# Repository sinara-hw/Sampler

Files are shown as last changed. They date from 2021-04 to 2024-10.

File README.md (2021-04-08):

# Sampler
ARTIQ - compatible 8 channel 16bit 1MS/s ADC card in EEM standard

## Design Files

Design files (schematics, PCB layouts, BOMs) can be found at [Sampler/Releases](https://github.com/sinara-hw/Sampler/releases).

## Wiki

More information can be found on the [wiki](https://github.com/sinara-hw/Sampler/wiki).

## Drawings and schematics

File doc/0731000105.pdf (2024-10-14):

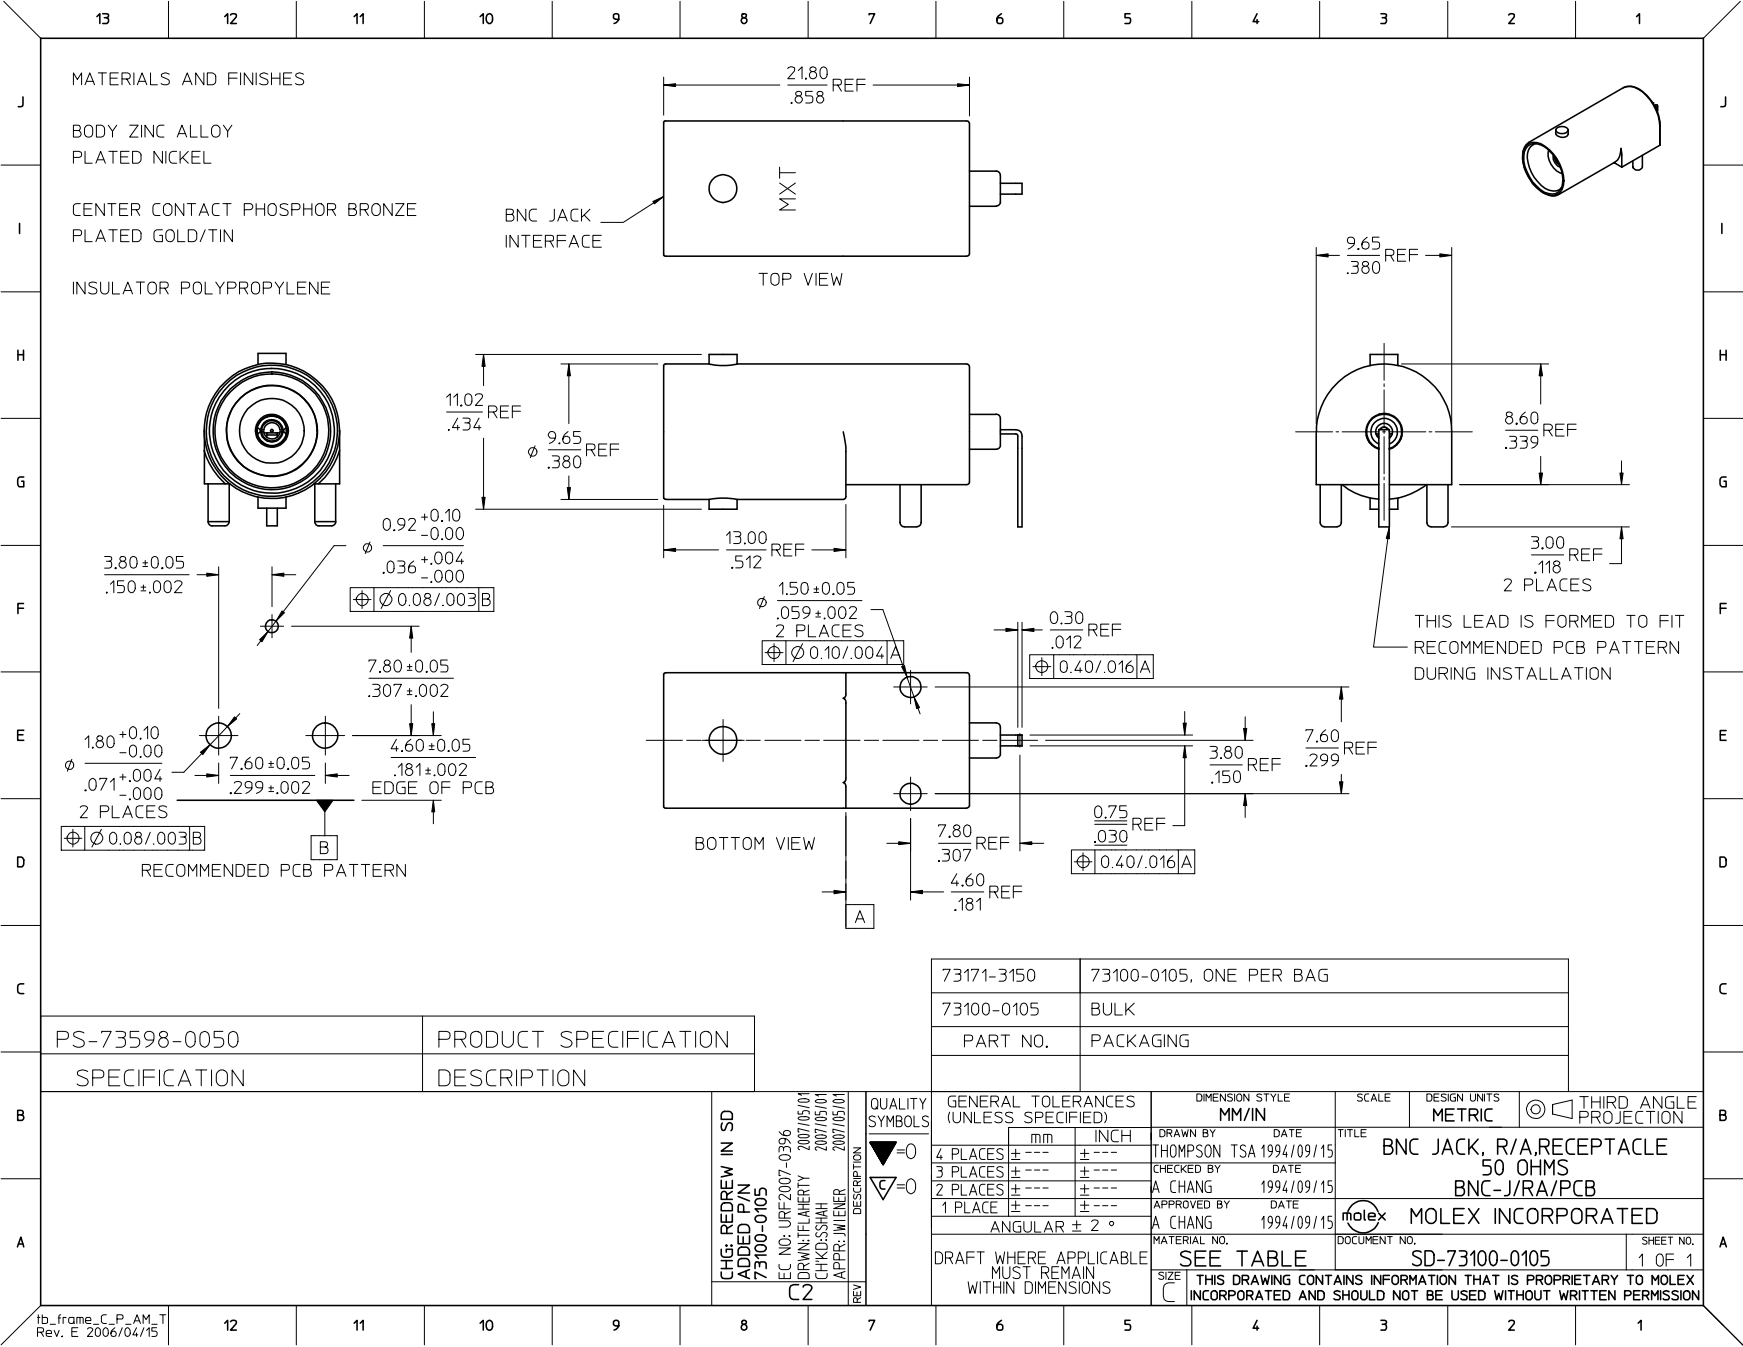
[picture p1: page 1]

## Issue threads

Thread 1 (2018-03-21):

Unexpectedly high noise in 1000x gain range

jordens, 2018-03-21:
Is 4.4 µV RMS, was 3.7 with Novogorny (14.3 vs 9.7 LSB RMS). The bandwidth limitation should be the same (the INA). Different full scale voltage (12/10) taken into account.
Maybe investigate this.

hartytp, 2018-03-23:
Firstly, to remind myself what we expect here.

- Input noise of the AD8253 at G=1k is 10nV/rtHz + 5pA/rtHz
- With 50R termination, that goes to ground through a pair of 1.8k resistors
- Assuming I've understood the [noise model](http://www.analog.com/media/en/training-seminars/tutorials/MT-065.pdf), we have: n = sqrt(10^2 + 5e-3*1.8e3 + 7.6^2)=13nV/rtHz
- 3dB BW=60kHz so (assuming dominant pole) is 96kHz
- Integrated noise is expected to be 4.0uVrms

So, the measured numbers fall roughly +-10% of the calculation. That's about as good an agreement with the theory as I'd expect, so I'm not overly worried about it -- particularly given that we only have 1 data point for each version. My suspicion is that this is just device to device variation, so it would be interesting to see some more statistics (e.g. more channels/more boards).

Note also that I'm not aware of any changes to the design that could cause this (the high-gain noise is dominated by the AFE which is unchanged between designs IIRC).

Closed 2018-04-12.

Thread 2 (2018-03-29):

Sampler v2.0 testing

sotirova, 2018-03-29:
**Noise measurement**:

Configuration:
- Sample rate: 1/12us
- 10k samples per measurement, averaging over 100 measurements
- looking at channels 6 and 7. 6 has the 50R termination on, 7 has it off
- looking at noise as a function of frequency for different gains.

Results:

|gain | noise w/ termination | noise w/o termination|
|---|---|---|
|1 | 1.78LSB (544.3uV) | 1.75LSB (535.6uV) |
|10 | 1.84LSB (56.2uV) | 3.09LSB (94.4uV) |
|100 | 3.47LSB (10.6uV) | 26.02LSB (79.4uV) |
|1000 | 13.87LSB (4.2uV) | 206.3LSB (63.0uV) |

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

Expectations:
- ADC transition noise is 1.5LSB RMS, which should limit the low gain noise measurement
- BW of ADC driver is 1.1MHz.
- InAmp noise model:
  - for G=1: 45nv/rtHz * sqrt(1.1MHz) * 1.6=72uV For G=1, this gives 0.23LSB*gain, lower for higher gains
  - Noise current BW is presumably 1/(2 * pi * 200k * 82pF) so 10kHz
  - No termination: 5pA/rtHz * 100k * sqrt(10kHz) * 1.6 = 80uV = 0.26LSB*gain
(actually, that's not totally correct, because the RFI filter reduces this slightly...)
  - Termination: 5pA/rtHz * 2k *sqrt(1.1MHz) * 1.6 = 16uV, so negligible

- ADC driver:
  - Johnson noise from 20k resistors is 18nV/rtHz so negligible
  - OpAmp is low noise compared to InAmp

So, expected noise is:

|gain | noise w/ termination | noie w/o termination|
|---|---|---|
| 1 | 1.5LSB | 1.5LSB |
| 10 | ... | ... |
| 100 | ... | ... |
| 1000 | ... | ... |

Comments:

- Spurs are most likely due to pickup.
- Adding/removing the two screening cans doesn't make a noticeable difference to the data
- Running from a linear PSU/wall wart doesn't make a difference, nor does connecting the linear PSU -ve output to GND.

hartytp, 2018-03-29:
Expected noise (summing InAmp vn + in and ADC contributions):

|gain|noise w/ termination|noise w/o termination|
|---|---|---|
| 1 | 1.5LSB (460uV) | 1.5LSB (460uV) |
| 10 | 1.6LSB (50uV) | 2.6LSB (80uV) |
| 100 | 4.8LSB (14.7uV) | 21LSB (64uV) |
| 1000 | 14.4 LSB (4.4uV) | 206LSB (63uV) |

Done on paper, so may contain mistakes ;) but suggests that the numbers we see are consistent with datasheet values.

- For no-termination, taking the current noise BW as 1/(2*pi*200k*82pF) = 10k

PS NB factor of 1.6 in BW above should be *inside* the sqrt.

hartytp, 2018-03-29:
Note also that we decided to increase the ADC driver BW to 1.1MHz for the v2 design. That makes the noise worse for higher gains than in the v1.0 design. The motivation for this was some simulations I did for laser intensity servo loops, where I found that increasing the ADC BW gave a decent improvement in servo BW/settling time.

Personally, I think the extra BW is worth the increased noise (which is still very low for the applications I have in mind). But, if anyone feels that we should tweak the BW for the v2.1 design, I'm happy to reconsider. If we do decrease the BW, we could increase the capacitor before the ADC, which might help to reduce sampling transients (although, we don't currently have any evidence that these are a problem in the current design).

sotirova, 2018-04-16:
**Bandwidth measurement**

We measured the bandwidth as a function of gain for both small and large input signal - ou measurements are consistent with what we expect to see from the design so everything seems to be working fine.

The large-signal bandwidths are very similar to the small-signal bandwidths.

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

Method:

- 1e4 samples
- sample rate 1/1.26e-5 Hz
- sampling channel 7 (no termination) driven by sinusoid from Keysight 33500B generator
- Small-signal BW measured using 2Vpp/gain
- Large-signal bandwidth measured using 15Vpp/gain

hartytp, 2018-04-18:
List of tests:
- [x] Noise spectrum with 0V inputs (all gains, w + w/o testing)
- [ ] Verify that noise does not depend on input voltage, using batteries as a voltage source (G=1, G=1k)
- [x] Small + large signal BW (all gains)
- [x] Cross-talk (https://github.com/sinara-hw/sinara/issues/489)
- [x] Temp co? Ticked off as not worth measuring. IMHO, feel free to untick if you want this/can be bothered to do it!
- [x] CMMR Ticked off because we measured this on the V1 design and the AFE hasn't changed, so I'm happy trusting that data.
- [x] Harmonic content at some fixed frequency (all gains, large signal?). Ticked off because I don't think this is worth measuring.

hartytp, 2018-04-18:
(baiscally, I'm happy that this board is now well tested, and the other measurements can all be finished off later as and when people really need them!)

Thanks again to all involved in the testing.

Closed 2018-04-27.

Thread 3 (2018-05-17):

gain error

jordens, 2018-05-17:
I am seeing a reading of 5V for 4.875V input and `0x7fff` for 9.76V input (pretty much the magic 1024/1000 error). I can't explain it from the schematics or the datasheets.
@hartytp @gkasprow have you also seen that?
Sampler/v2.1

gkasprow, 2018-05-17:
Was it the same in previous releases/batches?
I measured the DC response on rev1.0 and the difference was caused by the value of the RC filter which caused systematic error. This was fixed in rev 2.
I did not measure the DC response in rev2.x

gkasprow, 2018-05-17:
@jordens I assume you meant four references, REFOUT1..4. Or maybe REF_P2V5 and REF_P2V0?
Did you check the common mode of the ADC input? Maybe for some reason the DC offset appeared.
Please check also REF_P2V5 and REF_P2V0 on pin 1 and 7 of IC5. If you already checked, please check REFOUT1..4.

hartytp, 2018-05-17:
I don't think we saw that, no (although, I didn't do the testing myself so I can't be 100% sure).

jordens, 2018-05-18:
On one board REFOUT1,2 are 4.87V, REFOUT3,4 are ~4.9V. On another all four are 4.95V. All are definitely below 5.000V.

gkasprow, 2018-05-18:
So this explains the observation.
Can you measure voltage just at the C12 or pin 8 of ADC?

gkasprow, 2018-05-18:
Look at this voltage with scope as well. There is very little chance that reference oscillates.
I will recreate the issue but not earlier than Tuesday.
The ADC reference can be applied in two ways.
First - delivered to the REFOUT1..4, but then R10 must be removed (REFBFEN shorted to GND) and reference applied directly.
Second - delivered to the REF pin where it overrides internal reference. Internal reference has 250uA output current so can be easily overrided by external one.
It looks like the internal reference buffers are not real rail to rail amplifiers.
Did you check if the supply voltage is 5V? If it is slightly lower, that may be an issue and should be increased even to 5.25V by modification of 1 resistor. In such case this issue could be not detected on previous boards.
Another solution is to disable the buffers and apply the reference directly.

jordens, 2018-05-18:
No oscillations that I can see on REF or REFOUT1...4. I measured the 5V reference at C12.
P5V0A is also below 5V (~4.95V). Adding ~300k in parallel with R29 fixes it.

jordens, 2018-05-18:
I don't really like VDD=5.25V. And I don't know whether REFBUFEN=0, REFOUT1...4=5V, and VDD~4.99V would work. We could just simplify everything and lower the AFE gain and go with REF=4.096V. That also avoids complaints about "the ADC not doing 10.000V" and makes the math easier. Was/is the 1dB THD and 0.5dB SNR gain really worth it?

jordens, 2018-05-18:
I'll leave open until the fix has been committed to the repo or until this has landed on an errata list.

jordens, 2018-05-18:
I see you just did that. ;) Closing.

gkasprow, 2018-05-18:
5.25 is still within operating range and far below maximum voltage (6V). Another option is to connect the REF to all ref outputs.
Since many Samplers were produced, changing the reference value now may cause frustration at some point. We would have to indicate it on the panel.

jordens, 2018-05-18:
5.25V is at the end of the specified range for VDD.
If you connect a 5V REF to all REFOUT, are you sure that will work with e.g. VDD=4.99V (what I wondered above)?
Supporting two different VREF in the code is not that hard. It's probably less inconvenient than running around and patching all Sampler boards with the issue.

gkasprow, 2018-05-18:
To change reference, you need to replace the chip anyway.
That's true, taking into account tolerances of resistors and regulator reference, one can exceed 5.25V. We would need to use 0.1% resistors. VADJ tolerance is 12mV (roughly 1%) and set 5.2V to make sure 5.25 will not be exceeded.
Direct connection needs testing, but it's easy to be done.
But probably 4.096V range would be more stable in long-term.
It would be hard to achieve +/-10V range with 4.096 reference due to missing matched resistive dividers that provide such division rate.

jordens, 2018-05-18:
Yes. More a lesson for the future. I am OK with 5.2V for now.
I meant +- 10.24 V range (2.5 gain, easy conversion math, and +10 V strictly included, also what many other products do).

hartytp, 2018-05-18:
@jordens Thanks for tracking this down!

I wonder why we didn't see it on the board we tested. Was there a change between v2.0 and v2.1 that affects this? Did we get lucky with component tolerances giving us a higher supply voltage on the board we tested? Or, did we just miss it? Anyway, I'll look at it when I'm back in the lab.

Assuming the dividers work out okay (someone needs to sketch out what they would be), I agree that going to a +-10.24 span (4.096Vref) sounds like the right idea. For the time being, I'll apply the same patch as @jordens to increase the supply voltage to 5.2V.

gkasprow, 2018-05-18:
We can move to 1/5 gain easily, we have:
2x5k and 2x10k in one package.
At the moment we have gain of 10+10 /5 = 4
We can combine 10+10+5/5 = 5.
We can make it in next revision.

hartytp, 2018-05-18:
@gkasprow what dividers would you use on the reference voltage to create the common-mode offsets?

gkasprow, 2018-05-18:
Exactly.

gkasprow, 2018-07-25:
fixed

Closed 2018-05-18.

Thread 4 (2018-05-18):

Sampler errata

gkasprow, 2018-05-18:
- ~increase 5V to 5.25 to make more room for REF buffer.~
- [x] Use 4.096V reference and change AFE gain.

gkasprow, 2018-07-25:
fixed

Closed 2018-07-25.

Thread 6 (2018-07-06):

LDO + diodes

hartytp, 2018-07-06:
cf Zotino (need to check other designs as well...)

gkasprow, 2018-07-25:
ADC do not have negative rail, opamps don't care since they don't have GND terminal.
Sampler supply has power sequencing mechanism implemented so don't think we need Shottky diodes at the LDO output. Standard TVS works fine.

Closed 2018-07-27.

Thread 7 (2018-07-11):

SMPS current setting resistor should be 36k

hartytp, 2018-07-11:
cf https://github.com/sinara-hw/Zotino/issues/10

gkasprow, 2018-07-11:
@hartytp You are right. After I soldered 36K, the voltage dropped to +/-13V and current drawn from 12V dropped from 0.22A to 0.19A

Closed 2018-07-25.

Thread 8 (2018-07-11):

SMPS rating

hartytp, 2018-07-11:
https://github.com/sinara-hw/Zotino/issues/13

gkasprow, 2018-07-25:
In Sampler the IDC connector supply rails are disconnected by default.
I added a 0R resistor that can enable +12V as well.

Closed 2018-07-25.

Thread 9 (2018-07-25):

v2.2 review

gkasprow, 2018-07-25:
@hartytp @jordens I want to make production run of v2.2
Please have a look at the [schematics](https://github.com/sinara-hw/Sampler/releases/tag/Sampler%2Fv2.2rc1)
I modified the ADC range, input stage gain and reference generation.

hartytp, 2018-07-25:
Thanks Greg. I'll look at it with fresh eyes in the morning.

hartytp, 2018-07-25:
Before I forget though, there are a few issues in https://github.com/sinara-hw/meta/issues that are relevant and would be nice to fix now (e.g. if it's easy, it would be nice to swap the EEM connector ordering).

hartytp, 2018-07-26:
Relevant "meta" issues are:
- https://github.com/sinara-hw/meta/issues/3
- https://github.com/sinara-hw/meta/issues/2
- https://github.com/sinara-hw/meta/issues/1

Only https://github.com/sinara-hw/meta/issues/1 affects the schematic/layout.

gkasprow, 2018-07-26:
OK, I will swap the EEM connectors

gkasprow, 2018-07-26:
done.

hartytp, 2018-07-27:
Do you need to make any PCB changes for the EMC gaskets (e.g. ensure that mount holes are connected to PCB ground)?

Otherwise, looks good to me. Thanks!

gkasprow, 2018-07-27:
OK, I changed the holes to plated and connected to GND.

jordens, 2018-07-27:
Woa. Why exactly was that done? Is it needed and is this the right moment and place to do it?
* AFAICT this is the only board that has this. Now this is the only point where the crate connects to GND.
* It's irrelevant for for EMC shielding AFAICT. The slot between the board and the panel is still there.

hartytp, 2018-07-27:
@jordens my understanding is that we agreed that all EEM front panels should connect to ground at the PCB, rather than relying on the long inductive loop of the IDC to do it.

gkasprow, 2018-07-27:
Guys, I can add 0R not mounted by default.

gkasprow, 2018-07-27:
I will make these 0R mounted by default.

jordens, 2018-07-27:
I am ok with reliably connecting the front panel to GND. I just have a problem with doing it in one place through single a connection that does not look like it's meant to ground the entire crate: Does that angle bracket reliably connect the front panel, does it cut through the passivation? I'd like to first have a consensus how we want to "properly" ground the case and after that start connecting to the case in various places. I.e. I'd rather leave this connection open now.
Where are we relaibly connecting to the crate currently? AFAICT:
* Kasli SFPs: I don't think they get through the passivation reliably. Or does it work somewhat because the inside of the cutout is freshly cut?
* Kasli Power: No
* Crate to EEM front panel: Not cutting through the passivation on the non-shielded crates, yes on the shielded crates
* Zotino HD68 shield, Grabber shield, HD68IDC shield: probably not even pressing against it
* DIO-RJ45: same as Kasli-SFP

hartytp, 2018-07-27:
> I'd like to first have a consensus how we want to "properly" ground the case and after that start connecting to the case in various places. I

Absolutely agreed.

I'd like to try to get this consensus before we make more EEMs to avoid spreading bad design decisions further.

> I just have a problem with doing it in one place through single a connection that does not look like it's meant to ground the entire crate

When you say "ground the entire crate" you mean "join the Kasli/EEM ground to the crate ground", right?

> Does that angle bracket reliably connect the front panel, does it cut through the passivatedA?

@gkasprow

> Where are we relaibly connecting to the crate currently? AFAICT:

I can't remember the details now (@cjbe) but, I've had a few cases where EEMs have grounded the chassis in unexpected ways, causing surprising issues. Currently, the crate is neither properly isolated nor properly connected to the EEMs, which seems like the worst possible situation.

AFAICT, the best solution is to agree that going forwards that all EEMs should ground to the crate via their front panels.

hartytp, 2018-07-27:
> Where are we relaibly connecting to the crate currently? AFAICT:

NB As I said, we're preparing to buy a fresh batch of EEMs, so the plan would be to ensure that this fix is applied to all EEMs produced from now on. That way, it's not just sampler that does the grounding.

We can leave 0R resistors so users can isolate the grounds if they need to.

jordens, 2018-07-27:
All correct. But there are dozens of crates out there with the current configuration. If any user wants to use a new module we need to come up with a way to handle this properly.

hartytp, 2018-07-27:
Okay, so we agree that the long-term solution is connecting the FP to the circuit ground (modulo the issue you raise about checking that the way Greg is doing this will actually work)?

> But there are dozens of crates out there with the current configuration. If any user wants to use a new module we need to come up with a way to handle this properly.

Well, the current situation is bad in a few ways. I'm not sure that adding the grounding on new EEMs makes it worse. And, in any case, there are 0R resistors which can be DNPd

Personally, I'd advice users to find a way of grounding their Kaslis to their crates.

jordens, 2018-07-27:
These options to rework the board are not satisfactory solutions IMHO. It's undocumented, hard to get through to the board house or the end user without causing delays/misunderstandings. The default needs to be consistent and correct. The burden of proof is with the proposed new solution, not the status quo. Does this attempt at grounding the panel improve the situation? Given the current state, I don't see how it has a positive effect on safety, on EMI, on consistency, and grounding quality. The only areas that come to mind are EMI and ESD, right? Since nobody wants to run current through this connection, I don't see how the power grounding problem is affected or resolved. If those new Sampler boards won't be manufactured with the EMI lip panels systematically or if the angle brackets are not meant to or can't reliably connect the panel then the default should be DNP and once we have the full fleet updated we can switch the default BOM.

gkasprow, 2018-07-27:
I released production documentation with grounding resistors DNP. One can request their assembly during ordering or mount them later.

hartytp, 2018-07-27:
> The default needs to be consistent and correct.

Yes

> The burden of proof is with the proposed new solution, not the status quo

Sure: I think we all agree that the current status quo was not properly thought through and is not a good solution. Changing hastily to a new solution without due thought just multiplies the problems. So, let's see if we can settle on something better...

Currently, the EEM system, including power supply, tends to get grounded through unexpected/surprising paths. e.g. pressure put on an SFP cage that connects it to a front pannel, or an RJ45 DIO (grabber connectors?). That leads to unexpected and ill-defined grounding paths -- potentially involving sensitive lab equipment -- which is the absolute worst situation.

The proposal is to attempt to tie the circuit grounds to the chassis ground via their FPs. Lots of chassis provide grounding bolts or other grounding solutions, which we'd tie to a suitable ground point (e.g. all our racks are grounded, as are our optics tables).
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
hartytp, 2018-07-28:
The issues I'm referring to, which were already posted, are things like the RJ45 boards connecting the circuit ground to chassis ground atm. That lead to an odd case where when the 12V connector was mis-wired (and missing a ground connection) Kasli only powered on when an RJ45 board was plugged in (the RJ45 shield connected Kasli to the rack ground, which was electrically earthed). I've seen similar issues with the SFP cages on Kasli which can make intermittent contact with the FP in at least one version of the FPs we have.

NB If we defloat the SMAs on Urukul (as we've agreed to do IIRC) then those will tie Urukul's circuit ground to the PCB ground in any case.

@sbourdeauducq what's your point here? Are you arguing that our current grounding arrangement isn't unsatisfactory?

hartytp, 2018-07-28:
AFAICT, the only good reason that's been raised not to connect the FP ground to circuit ground is if it won't actually work properly (e.g. due to anodisation of the FP).

sbourdeauducq, 2018-07-28:
No, I just want to make sure that @cjbe's problems get addressed in this iteration, so that we end up with 2 different grounding schemes to deal with and not 3.

hartytp, 2018-07-28:
Another "surprising" issue I've seen with the current grounding arrangement (reported elsewhere, but repeated for those who weren't following that discussion).

Before I de-floated the clock input connectors on Kasli, I was driving a floating Kasli board clock input from a synth. That lead to the synth ESD protection tripping, which is something I take very seriously, as I've seen this kill 20k synths before. De-floating the SMA fixed the problem. However, if one does this without grounding Kasli via the chassis (or some other suitable means) then the only electrical ground is via the synth/clock SMA, which is not a good place to be in at all. To fix this, I ended up both defloating the SMA and adding a grounding strap to my Kasli to bond it to my main earthing ground.

All the grounding issues that I'm aware of our group having seen have been reported and discussed. AFAICT, they will all be solved by connecting the EEMs to a grounded chassis, which is effectively what we're doing now.

hartytp, 2018-07-28:
Another way of putting all this:
- In some cases it is necessary to isolate grounds for noise purposes
- however, the correct approach to this is not to isolate all grounds by default (what we did in v1 boards effectively), as that creates the problems we've seen
- instead, a better solution is to tie all grounds together by default, but to give users the option of isolating ground loops in the rare cases that it's actually required. This is what I'd like to see done in v2.0. eg leaving the plastic insulating washers in to allow us to float clock SMAs if we want to, but by default using 0R resistors to ground all SMAs to the chassis/PCB ground

hartytp, 2018-07-29:
Oh and the other "unexpected" grounding issue that crops up in the current design is when the USB cable becomes the only mains grounding point so things can behave differently depending on whether USB connected or not. E.g. the synth was issues only happened when I removed the USB cable

gkasprow, 2018-07-30:
Usually we provide central grounding at the supply rail on the backplane. Since we don't have backplane, such grounding should be done on Kasli or if we use backplane SMPS module, it should be there, just at the DC module output.
In addition, panels are usually connected with GND either directly or using parallel RC network.
In case of RC networ it is to mitigate DC ground-loops and provide short-rircuit for EMI so the RF power path is shorted to chassis as close to the entry as possible.
So the main grounding point is central, close to the supply and all others are to mitigate EMI issues.

hartytp, 2018-07-30:
> So the main grounding point is central, close to the supply and all others are to mitigate EMI issues.

With the new Schroff FPs you're ordering, will the barrel connector on Kasli ground the PSU to the chassis via Kasli's FP?

gkasprow, 2018-07-30:
It should be grounded after the supply passes via CMCs. So grounding at the entry is not best option. It's better to ground it at the panel fixing to the PCB

hartytp, 2018-07-30:
@gkasprow okay.

I'm still not clear though: are you satisfied that the front panels for the next batch of EEMs will provide a good ground connection between the PCB ground and the chassis ground? The old panels did not seem to do that.

gkasprow, 2018-08-04:
The old panels did not do that. New panels are designed to do that so that should be enough.

Closed 2018-08-04.

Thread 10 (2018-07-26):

Lots of text missing in PDFs

hartytp, 2018-07-26:

hartytp, 2018-07-26:
Also, SHDN for IC1.

Some Altium bug?

hartytp, 2018-07-26:
I take it back. At least in my PDF viewer, there is lots of text missing from the PDF, making the review hard

gkasprow, 2018-07-26:
OK, I regenerated with AD18 and it is fine.

hartytp, 2018-07-27:
@gkasprow Sorry for the delay, where are the new schematics?

gkasprow, 2018-07-27:
[here](https://github.com/sinara-hw/Sampler/releases/tag/Sampler%2Fv2.2rc1)

Closed 2018-07-26.

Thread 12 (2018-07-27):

Lower ref Vcc?

hartytp, 2018-07-27:
Shouldn't be a problem, but there is also no need for this to be +12V, just heats the reference up more than we need to. >6V5 would be fine

gkasprow, 2018-07-27:
done.

Closed 2018-07-27.

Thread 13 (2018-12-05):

Change BNC connectors

dtcallcock, 2018-12-05:
Sampler is the only place in Sinara where one is forced to use BNCs and an 8HP panel.

Standardising all boards to 4HP may be advantageous for [a future backplane](https://github.com/sinara-hw/meta/issues/30#issuecomment-444467090).

MMCX would be an obvious choice as we are already using it for the Sayma v2 AFE analog inputs and Stabilizer aux digital inputs. However, they are a bit on the small side and easy to disengage compared SMB/MCX so one might worry about mechanical robustness. SMC/Micro BNC/LEMO all seem somewhat less ubiquitous and more expensive. My slight preference would be for MCX, but it would be good to hear from people with more experience.  I'm not totally sure how you would isolate this kind of connector from the front panel though (just a clearance hole?).

Even if we all agreed this is a brilliant idea, it probably doesn't warrant a board revision right away.  I did want to leave an issue open in this repository for future reference though.

dhslichter, 2018-12-05:
Just need to think a little about crosstalk (granted, BNC is not great for this either).  But I agree that MCX or SMB or other smaller connectors would be nice.

dtcallcock, 2018-12-05:
@hartytp makes the point that:

> Personally, I also like BNCs. Much quicker to swap in and out. Much easier to make ones own cables to length quickly and cheaply.

It seems that MCX is even easier to swap in and out than BNC and connectors are available that, at first glance, don't look any harder to assemble than a BNC connector (eg. [this](https://www.digikey.com/product-detail/en/molex-llc/0733660020/WM5388-ND/2755904) RG-316 connector).

However I do buy the argument that most labs have a lot of BNC stuff around and a proliferation of random connectors across Sinara should be avoided (hence my opinion that we should just pick one general BNC replacement).  The board could also optionally ship with 8 BNC pigtails.

> Just need to think a little about crosstalk (granted, BNC is not great for this either).

A random search suggests that MCX might have >70dB RF leakage (compared to >100dB for an SMA and >55dB for BNC).  MMCX seems similar to MCX and SMB seems similar to BNC.  Exact numbers depend on mfg/cable obviously.

dhslichter, 2018-12-05:
SMB leakage is lousy, so I generally don't like them.  If MCX is better then rock on.

gkasprow, 2018-12-19:
DSO203? I have such model for 4 years or so and can confirm that these probe connectors work reliably.

gkasprow, 2019-02-18:
The assembly house asked us to make some cosmetic changes that would improve the production yield.
I will also add mounting holes for CPCIS adapter. Do we plan to change the BNC connectors and switch to 4HP?

gkasprow, 2019-02-18:
MCX version would look like this
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

hartytp, 2019-02-18:
I’m happy with either BNC or MCX

jordens, 2019-02-18:
Go for mcx.

gkasprow, 2019-02-18:
Do you want MCX-BNC adapters to be delivered with Sampler?
Would such cable be fine?
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

They cost roughly 2EUR/pc

jordens, 2019-02-19:
Ah. One thing to check: those small mcx to sma bullet adapters. Do they fit or is the pitch to small for sma?
Yes. I'd include 8 of those pigtails.

gkasprow, 2019-02-19:
I tried with the biggest SMA-MCX adapters I could find and it will work. Of course, SMA needs to be attached prior to plugging. I do not recommend using these adapters with thick and long SMA cables because they will add tension to the MCX connectors and the PCB. Cable adapters seem to be a better choice.

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

gkasprow, 2019-02-19:
There is no collision with the handle
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

dtcallcock, 2019-02-27:
+1 for MCX and pigtails

hartytp, 2020-03-21:
@gkasprow @jordens and others, do we want to do anything here for the next revision, or leave this to further down the line? I'm okay with MCX so long as we ship with MCX to BNC pigtails.

gkasprow, 2021-01-22:
The Sampler board can be ordered with MCX adapter board, so I'm leaving it as it is now with BNCs.

dtcallcock, 2021-07-06:
Added note about this to wiki.

gkasprow, 2021-07-06:
Btw, one can already order such Samplers. TS did a production run AFAIK.

Closed 2021-07-06.

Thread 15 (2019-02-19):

production feedback

gkasprow, 2019-02-19:
PCB needs minor correction:
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

gkasprow, 2021-01-22:
fixed

Closed 2021-01-22.

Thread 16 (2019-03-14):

power supply annotation incorrect

hartytp, 2019-03-14:
It says Ra should be 36R not 36k

gkasprow, 2021-01-22:
fixed

Closed 2021-01-22.

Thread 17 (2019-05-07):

Wiki: update link to ADC datasheet

airwoodix, 2019-05-07:
to https://www.analog.com/media/en/technical-documentation/data-sheets/232016fb.pdf

jordens, 2019-05-07:
https://github.com/sinara-hw/Sampler/wiki/Home/_compare/7359c9903639df1e812984811c5cad37bb31cfb9...dff57510bae83d6749528461c37abe0dab83a38b

thanks!

Closed 2019-05-07.

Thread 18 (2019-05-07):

Wiki: update EEM connector pinout

airwoodix, 2019-05-07:
To match Sampler v2.x:
- add `ADC-SDOA` output to EEM1 pair 1 (and shift the other `SDOx` accordingly);
- shift `ADC-SDOA` output on EEM0 to pair 1;
- add `ADC-SDR` input to EEM0 pair 2.

Although pretty obvious, a direction indication would be great I think.

airwoodix, 2019-05-08:
Great, thanks a lot! Changes done.

Closed 2019-05-08.

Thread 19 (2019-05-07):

IC19 not populated and IC18/IC19 labels exchanged on silk screen

airwoodix, 2019-05-07:
This might be known already but a quick scan through the issues did not hit. Sorry for the noise if that's the case.
If I'm not mistaken, the silk of Sampler v2.2 says `IC18` where it should be `IC19` (PGIA SR `miso` LVDS driver).
Also, is there a good reason to not populate this driver by default? It's pretty annoying to solder once the EEM connectors are mounted. This is also confusing since the ARTIQ [coredevice driver](https://github.com/m-labs/artiq/blob/master/artiq/coredevice/sampler.py#L94) has a `get_gains_mu` method which won't work without that chip (or am I overlooking something here? I didn't test that).
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

gkasprow, 2019-05-07:
You are right, the IC18/IC19 labels are swapped. So the PGIA0-MISO is not connected. The only use case for this signal is verification of  IC10/IC11 SPI operation.

airwoodix, 2019-05-08:
Thanks for the confirmation. I think it's nice to be able to read back the gain settings for the PGIAs rather than keeping track of them is software. Is there a big cost factor associated with populating these chips in the factory? The chips themselves are well below 1 € for large quantities, aren't they?

hartytp, 2019-05-08:
Nb reading back the pgia gain can change it e.g. if it was set to something other than the device db value in a previous kernel.

I did wonder if it’s worth introducing a SR rtio pho with backing state on the FPGA to deal with this, but it’s a bit of a corner case so prob not worth the added complexity.

jordens, 2019-05-08:
You can change `get_gains_mu` so that it doesn't have side effects. See `Urukul.get_att_mu`.
A backing state in the FPGA is not really a solution. E.g. for the really interesting case where you drive the trap RF from Urukul and want your ion to survive a Kasli reboot. It's doable currently and backing state in the FPGA would actively prevent that.

hartytp, 2019-05-08:
> You can change get_gains_mu so that it doesn't have side effects. See Urukul.get_att_mu.

Aah, nice, I hadn't seen that.

> E.g. for the really interesting case where you drive the trap RF from Urukul and want your ion to survive a Kasli reboot. It's doable currently and backing state in the FPGA would actively prevent that.

Point taken. I hadn't considered that use case (and, it wouldn't work for us since we clock our Urukul from Kasli).

gkasprow, 2019-05-08:
@jordens that is true providing that there was no activity in the shift register after latching its content :)

jordens, 2019-05-08:
@gkasprow Yes. We do assume SPI protocol. Then any previous transaction is guaranteed to have ended in raising CS and thus latching from the SR to the outputs ensuring they are the same.

airwoodix, 2019-05-08:
To summarize: with `Sampler.get_gains_mu` implemented like `Urukul.get_att_mu`, there is a non-invasive way of getting the gain settings, so populating the PGIA-MISO line driver by default would make sense, correct?

jordens, 2019-05-08:
Sure. Populating it always made sense. I don't know why it was DNP ed in v2.2.

gkasprow, 2019-05-08:
Some of you requested to DNP it.
Take into account that you can read the gain settings only once since readout is destructive.

jordens, 2019-05-09:
No. Readout does not need to be destructive. See the explanation above.
And if there was such a request it should always be tracked as an issue and as a commit message. That allows review and discussion.

gkasprow, 2019-05-09:
to make the readout non-destructive, you must connect MOSI with MISO to clock in data that you clock out :)

jordens, 2019-05-09:
Again no. Lower cs, clock in zeros while clocking out the current state, then clock that same state which you just read back in while ignoring the zeros coming out, finally raise cs (activating the same state non destructively).

gkasprow, 2019-05-09:
@jordens ACK. But you have to make read-write cycles. You cannot read it twice like in a regular SPI IO registers

jordens, 2019-05-09:
For each bit written into the shift register one is being read. That's intrinsic to four wire SPI.
But yes you need to shift twice the length of the register to do such a nondestructive read.

marmeladapk, 2019-05-22:
@gkasprow This buffer is required to check if PGIA works properly in our production tests. We at Creotech are strongly for mounting it.

gkasprow, 2019-05-22:
I was requested to DNPit. It was mounted in earlier versions. It's no problem to mount them.

gkasprow, 2021-01-22:
swapped labels, IC19 will be mounted

Closed 2021-01-22.

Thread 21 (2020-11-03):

MFG issues

gkasprow, 2020-11-03:
R0402_47K_1%_0.0625W_100PPM has wrong PN field which indicated 51k resistor

gkasprow, 2021-01-22:
fixed also R0402_51K_1%_0.0625W_100PPM which PN field indicates 47k resistor

Closed 2021-01-22.

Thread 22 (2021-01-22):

rev1.3 changelog

gkasprow, 2021-01-22:
- removed some unused shielding clips around the SMSP to make room for CPCIS fixing holes and correct EEM connectors positions

kaolpr, 2021-01-22:
You mean 2.3?

gkasprow, 2021-01-22:
yes:)

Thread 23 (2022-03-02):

Sampler shield lid part number?

alandoak, 2022-03-02:
Are the shield lid and clips for the Sampler, which are no longer populated, standard parts that I can order?

Any info would be appreciated: manufacturer, part number, distributor, etc.

gkasprow, 2022-03-02:
So far nobody requested them.
These are HARWIN S1411-46R compatible with [these](https://www.harwin.com/products/S01-806005KIT/) shields

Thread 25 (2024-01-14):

missing protection diodes

gkasprow, 2024-01-14:
The ADC might be in danger when overdriven from the front end, which can quickly go up to +/- 10V with currents up to 65mA. The only limit is a 51Ohm resistor. This is usually enough to trigger latch-up in most CMOS ICs.
I suggest adding protection diodes at the input of the ADC.

hartytp, 2024-01-15:
Can that happen in practice? I thought the divider between the InAmp and the OpAmp should prevent an input overdrive from leading to the ADC being overdriven?

gkasprow, 2024-01-15:
You are right! My colleague is re-using part of ADC with the driver (but without a divider), and I noticed that ADC might suffer damage. But that's not our case.
When you set the input range to 1V and apply 10V, the InAmp will produce, in the worst case, 11.5V.
We have an OutAmp with a gain of 1/5 and an offset of 1.7066. This means that the max voltage ADC would see is 4.3V.
No worry, then.

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

Closed 2024-01-15.

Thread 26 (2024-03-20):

Sampler DIOT with MCX

gkasprow, 2024-03-20:
We plan to make new revisions of all modules supporting the DIOT connector (we will leave the EEM option as well)
DIOT is 6 HP, so there won't be a place for BNC.
Instead, we could include 8 BNC adapters
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

jordens, 2024-03-20:
The shields touching (Sampler is differential) and the BNC being bulkhead mount troubles me.

gkasprow, 2024-03-20:
BNC Micro is another option, but it is not very popular though.
Yet another idea is to make a simple 1U panel that would hold all BNC-MCX pigtails. One could mount it below the DIOT crate.

gkasprow, 2024-07-10:
We can also make an 8-channel SMA.
But since we have a 6HP panel, we can also fit 8 BNCs
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

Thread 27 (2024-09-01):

DIOT version

gkasprow, 2024-09-01:
Let's go for BNC version
- [ ] Four BNC channels are placed on the main board, and four additional channels are placed on tiny mezzanine.
- [ ] Mezzanine must be secured firmly by 2 spacers and screws
- [ ] Channel numbering must be as in other boards
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
- [ ] Use [standard](https://www.we-online.com/components/products/datasheet/61301621821.pdf) low cost 2.54 goldpin connectors and headers; nothing fancy, just ordinary ones.
We will fit easily with 10 or 12mm stacking height
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
- [ ] Make sure we have enough place for BNC plugs
- [ ] Use [DI/OT template](https://github.com/sinara-hw/DIOT-Template/issues/1), don't modify the template files! (EEM_Connectors.SchDoc, CPCIS_Connectors_P1_P6.SchDoc)
- [ ] commit as SAMPLER-DIOT
- [ ] include spacers, nuts and washers into the design so it appears in BOM
- [ ] don't touch analog design, DC/DC layout, ground cutouts
- [ ] BNC shell must be isolated from the panel! Make sure we will fit 3D-printed isolated washers from inside

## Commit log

2018-03-21 fixed issues #489
    [ADC_8CH.SchDoc, Input_channel.SchDoc, LVDS_IFCA.SchDoc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]
2018-03-28 added panel design
    [Sampler.PrjPCB]
2018-07-25 rc2.2 fixed issues #3 #4 #7
    [ADC_8CH.SchDoc, Input_channel.SchDoc, Sampler.PrjPCB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]
2018-07-27 production v2.2
    [ADC_8CH.SchDoc, Input_channel.SchDoc, LVDS_IFCA.SchDoc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]
2021-11-26 added nuts and washers to the BOM
    [Sampler.PrjPCB, Sampler.schdoc]
2024-02-19 v2.3.1 rc1
    [ADC_8CH.SchDoc, Sampler.PrjPCB, Sampler.schdoc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]
2024-02-21 added missing files
    [Panel_Sampler_4HP.PcbDoc]
2024-10-14 SAMPLER-DIOT firts commit
    [ADC_8CH.SchDoc, Adapter.SchDoc, CPCIS_Connectors_P1_P6.SchDoc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]
2024-10-26 Adapter board connector placment compleat
    [Adapter.SchDoc, CPCIS_Connectors_P1_P6.SchDoc, DIOT_Power_Supplies.SchDoc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]
2024-10-28 100% connection
    [ADC_8CH.SchDoc, CPCIS_Connectors_P1_P6.SchDoc, DIOT_Power_Supplies.SchDoc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]
2024-10-29 Layout fix, BNC bord update, 4 connector wersion
    [DIOT_Sampler.PCBDOC, Sampler.schdoc]
2024-11-11 100% routing V2.0
    [DIOT_Sampler.PCBDOC, DIOT_Sampler.PrjPCB, EEM_Connectors.SchDoc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]
2024-11-11 PRoject nama change go Sampler_DIOT
2024-11-15 update layout and insert BNC separator model
    [Adapter.SchDoc, CPCIS_Connectors_P1_P6.SchDoc, DIOT_Sampler.PCBDOC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]
2024-11-15 move adapter model to a proper position
    [Sampler_DIOT.PCBDOC]
2024-11-20 Buffor roll back
    [Sampler_DIOT.PCBDOC, Sampler_DIOT.PrjPCB, old_Sampler_DIOT.PCBDOC]
2024-11-22 fix BNC mechanical issiue
    [DIOT_Sampler_Adapter.PCBDOC, EEM_Connectors.SchDoc, Sampler.schdoc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]
2024-11-23 fix Mechanical layers and ESD Strip
    [EEM_Connectors.SchDoc, Sampler.schdoc, Sampler_DIOT.PCBDOC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]
2024-11-23 fix front plate mounting holes center position
    [Sampler_DIOT.PCBDOC]
2024-11-23 update2 21.11.2024
    [Sampler_DIOT.PCBDOC]
2024-11-24 LVDS lenght trim
    [Sampler_DIOT.PCBDOC]
2024-11-24 Some truck spacing increase
    [Sampler_DIOT.PCBDOC]
2024-11-24 Rebuild P3V3 power layout
    [DIOT_Sampler.PcbLib, DIOT_Sampler.SCHLIB, DIOT_Sampler_Adapter 20 mm spacing.PCBDOC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]
2025-01-10 Fix BNC Position, Adapter board layout 100%, Sequencer schematic and layout upgrade
    [CPCIS_Connectors_P1_P6.SchDoc, Sampler.schdoc]
2025-01-10 Adapter board layout upgreade
    [DIOT_Sampler_Adapter.PCBDOC]
2025-01-26 Differential truck were removed from the DIOT-KEY area, the adapter board was reduced by 1mm from the top and bottom so that it would fit into the RACK housing, Compiler masks were applied to unused 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
    [CPCIS_Connectors_P1_P6.SchDoc, DIOT_Power_Supplies.SchDoc, DIOT_Sampler_Adapter.PCBDOC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]
2025-01-28 Adapter board - Release for manufacture
    [DIOT_Power_Supplies.SchDoc, DIOT_Sampler_Adapter.PCBDOC, DIOT_Sampler_Upper_BNC.PrjPcb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]
2025-01-31 BNC connector PN updatee
    [Sampler.schdoc, Sampler_DIOT.PcbLib, Sampler_DIOT.PrjPCB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]
